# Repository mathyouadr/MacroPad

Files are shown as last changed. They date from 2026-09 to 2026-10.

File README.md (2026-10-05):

# MacroPad

Pavé de 9 touches programmables basé sur un Raspberry Pi Pico (RP2040) sous CircuitPython.
Il se branche en USB et est reconnu comme un clavier (raccourcis + touches média), sans driver.
Un logiciel PC permet de changer l'action de chaque touche sans reprogrammer le Pico.

Projet réalisé par Mathyou ANDRE dans le cadre du chef-d'œuvre Bac Pro CIEL, au LPP Le Marais Sainte-Thérèse.

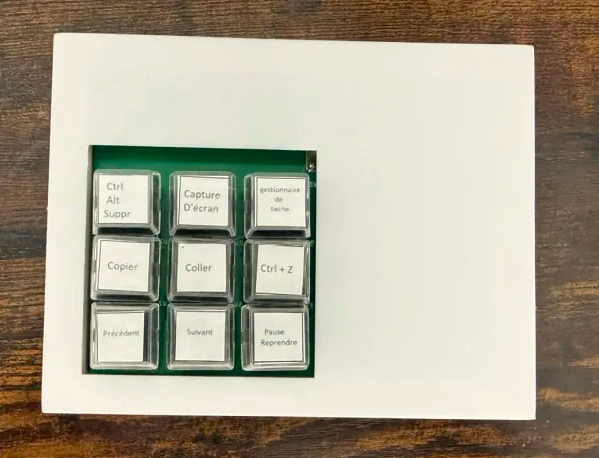
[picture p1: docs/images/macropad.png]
MacroPad assemblé


## Sommaire

- [Structure du projet](#structure-du-projet)
- [Firmware](#firmware)
- [Configurateur PC](#configurateur-pc)
- [Configuration des touches](#configuration-des-touches)
- [Matériel](#matériel)
- [Licence](#licence)

## Structure du projet

```text
MACROPAD/
├── firmware/        Code CircuitPython à copier sur le Pico (boot.py, code.py)
├── configurator/    Logiciel PC de configuration (Python / Tkinter)
├── hardware/
│   ├── schematic/   Schéma électronique (PDF, PNG, source EasyEDA)
│   ├── pcb/         PCB : source Fritzing, Gerber pour la fabrication, PDF
│   ├── case/        Boîtier 3D (Fusion 360 + STL pour l'impression)
│   └── libraries/   Composants Fritzing nécessaires pour ouvrir le PCB
└── docs/            Images du README
```

## Firmware

Code CircuitPython du dossier `firmware/`, à copier sur le Raspberry Pi Pico.

- `code.py` : lit les 9 touches, envoie les raccourcis clavier/média en USB HID,
  et reçoit la configuration du logiciel PC par le port série.
- `boot.py` : cache le lecteur `CIRCUITPY` au démarrage (voir [Mode maintenance](#mode-maintenance)).

### Installation

1. Installer CircuitPython sur le Pico (fichier `.uf2` depuis circuitpython.org).
2. Copier le dossier `adafruit_hid` de l'*Adafruit CircuitPython Library Bundle*
   dans `CIRCUITPY/lib/`.
3. Copier `firmware/code.py` puis `firmware/boot.py` à la racine de `CIRCUITPY`.
4. Débrancher puis rebrancher le Pico (`boot.py` ne s'exécute qu'au démarrage).

### Mode maintenance

Une fois `boot.py` installé, le lecteur `CIRCUITPY` n'apparaît plus sur le PC.
Pour y accéder à nouveau (mise à jour du code), **maintenir SW1 enfoncé en branchant le Pico**.

## Configurateur PC

Logiciel Python / Tkinter du dossier `configurator/`, pour lire et modifier l'action de chaque touche.

### Lancement

Nécessite Python 3 :

```bash
cd configurator
pip install -r requirements.txt
python main.py
```

### Utilisation

1. Brancher le MacroPad, choisir son port COM puis cliquer sur **Connecter**.
   La configuration actuelle du Pico est chargée automatiquement.
2. Modifier les touches. En type `keyboard`, écrire les touches séparées par `+`
   (ex. `CONTROL+SHIFT+ESCAPE`) ; en type `media`, écrire l'action (ex. `PLAY_PAUSE`).
   Voir les [valeurs possibles](#valeurs-possibles).
3. Cliquer sur **Envoyer au Pico**.

Les boutons **Sauvegarder / Charger fichier** utilisent `macropad_config.json`
dans le dossier courant.

### Générer un exécutable Windows (optionnel)

Pour utiliser le configurateur sur un PC sans Python :

```bash
cd configurator
pip install pyinstaller
pyinstaller main.spec
```

L'exécutable est créé dans `configurator/dist/MacroPad-Configurator.exe`.

## Configuration des touches

### Configuration par défaut

| Touche | GPIO | Action |
|---|---|---|
| SW1 | GP28 | Ctrl + Alt + Suppr |
| SW2 | GP27 | Capture d'écran (Win + Shift + S) |
| SW3 | GP26 | Gestionnaire des tâches (Ctrl + Shift + Échap) |
| SW4 | GP22 | Copier (Ctrl + C) |
| SW5 | GP21 | Coller (Ctrl + V) |
| SW6 | GP20 | Fermer l'onglet (Ctrl + W) |
| SW7 | GP19 | Piste précédente |
| SW8 | GP18 | Piste suivante |
| SW9 | GP17 | Lecture / Pause |

### Valeurs possibles

- **Touches clavier** : `A`–`Z`, `F1`–`F12`, `CONTROL`, `ALT`, `SHIFT`, `WINDOWS`,
  `DELETE`, `ESCAPE`, `ENTER`, `TAB`, `SPACE`
- **Actions média** : `PLAY_PAUSE`, `NEXT_TRACK`, `PREVIOUS_TRACK`,
  `VOLUME_UP`, `VOLUME_DOWN`, `MUTE`

### Stockage et protocole série

La configuration est stockée dans `/config.json` sur le Pico.
Si le fichier est absent, la configuration par défaut de `code.py` est utilisée.

Format d'une touche :

```json
{"sw1": {"type": "keyboard", "keys": ["CONTROL", "ALT", "DELETE"]},
 "sw9": {"type": "media", "action": "PLAY_PAUSE"}}
```

Commandes série (une par ligne) :

| Commande envoyée | Réponse du Pico |
|---|---|
| `GET_CONFIG` | `CONFIG_DATA:{...}` |
| `CONFIG:{...}` | `OK` ou `ERROR` |

## Matériel

Chaque switch relie son GPIO au 3V3. Le firmware active la résistance de pull-down interne.

- **Schéma** : `hardware/schematic/schematic.pdf`
- **PCB** : conçu avec Fritzing 0.9.9 (`hardware/pcb/MACROPAD-FRIT.fzz`).
  Pour l'ouvrir, importer d'abord les composants de `hardware/libraries/fritzing/`.
  Les fichiers de fabrication sont dans `hardware/pcb/gerber.rar` (visualisables avec gerbv).
- **Boîtier** : `hardware/case/macropad-case.stl` pour l'impression, `.f3d` pour le modifier dans Fusion 360.

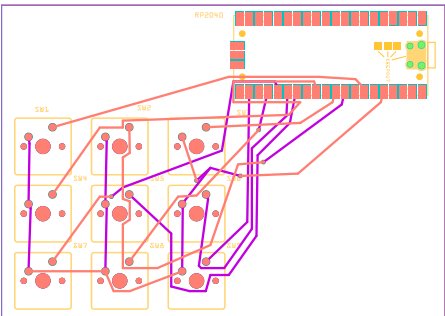
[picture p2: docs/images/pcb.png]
Routage du PCB


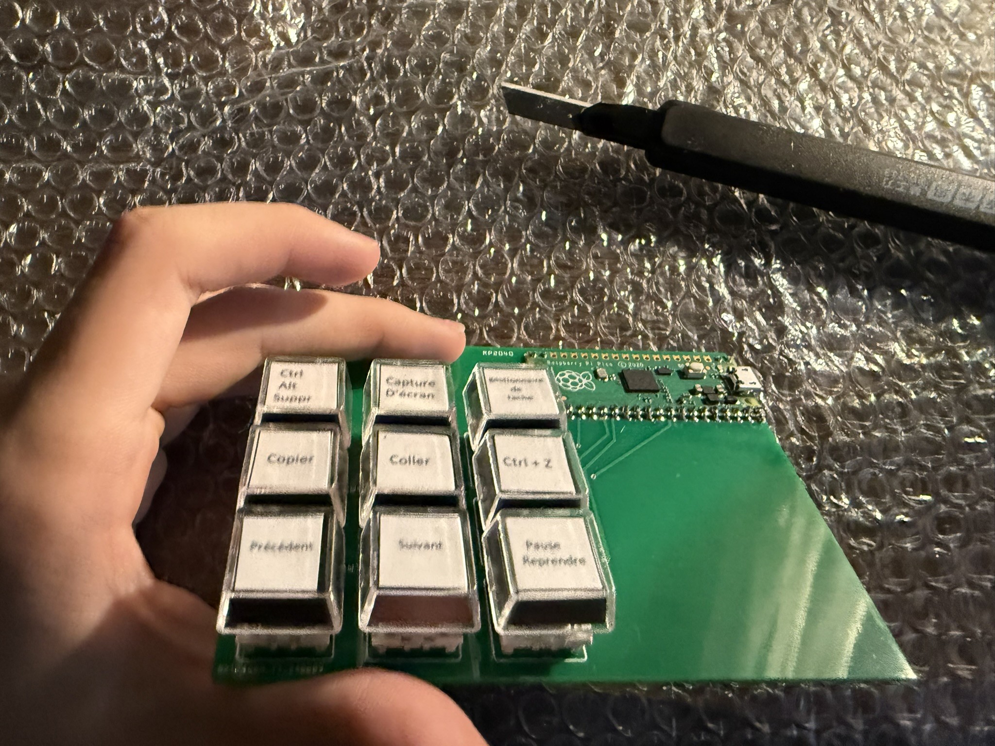
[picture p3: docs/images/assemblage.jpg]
Assemblage du PCB : soudure des switches mécaniques et du Raspberry Pi Pico


## Licence

MIT — voir [LICENSE](LICENSE).

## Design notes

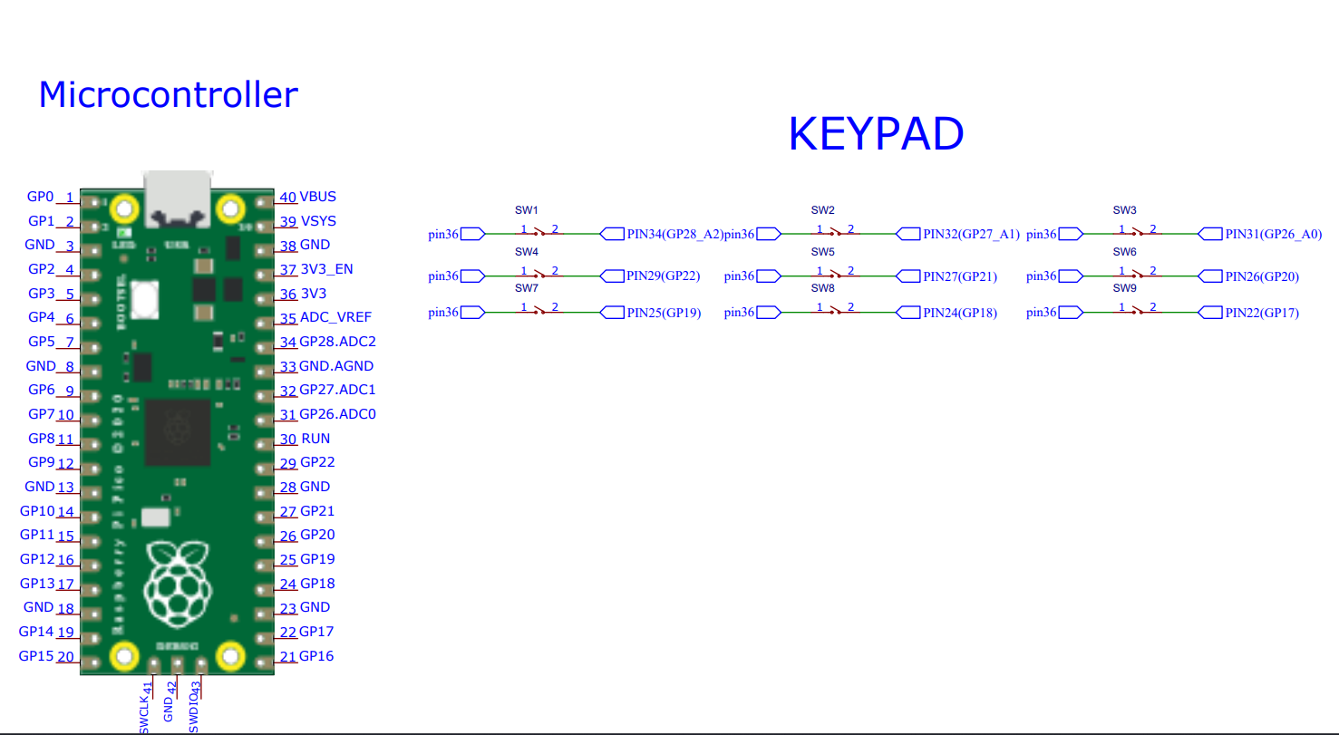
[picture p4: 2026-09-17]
hardware/schematic/schematic.png

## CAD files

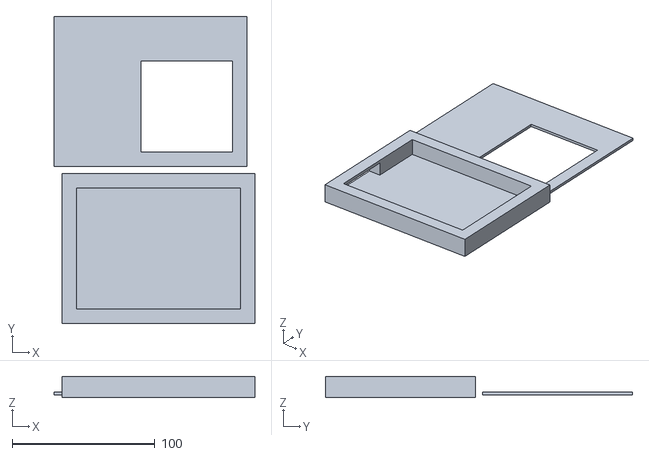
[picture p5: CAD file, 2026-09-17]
hardware/case/macropad-case.stl
140.7 x 215.0 x 15.0

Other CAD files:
hardware/case/macropad-case.f3d

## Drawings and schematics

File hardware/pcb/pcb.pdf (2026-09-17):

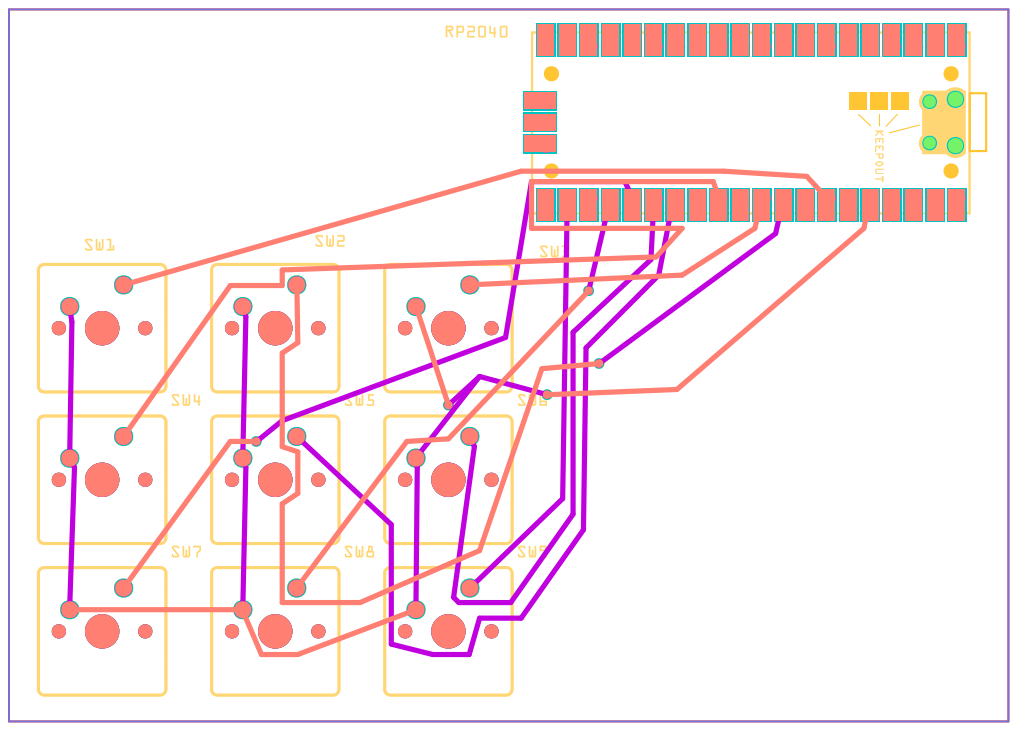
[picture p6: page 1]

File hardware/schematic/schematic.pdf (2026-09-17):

# Microcontroller

# KEYPAD

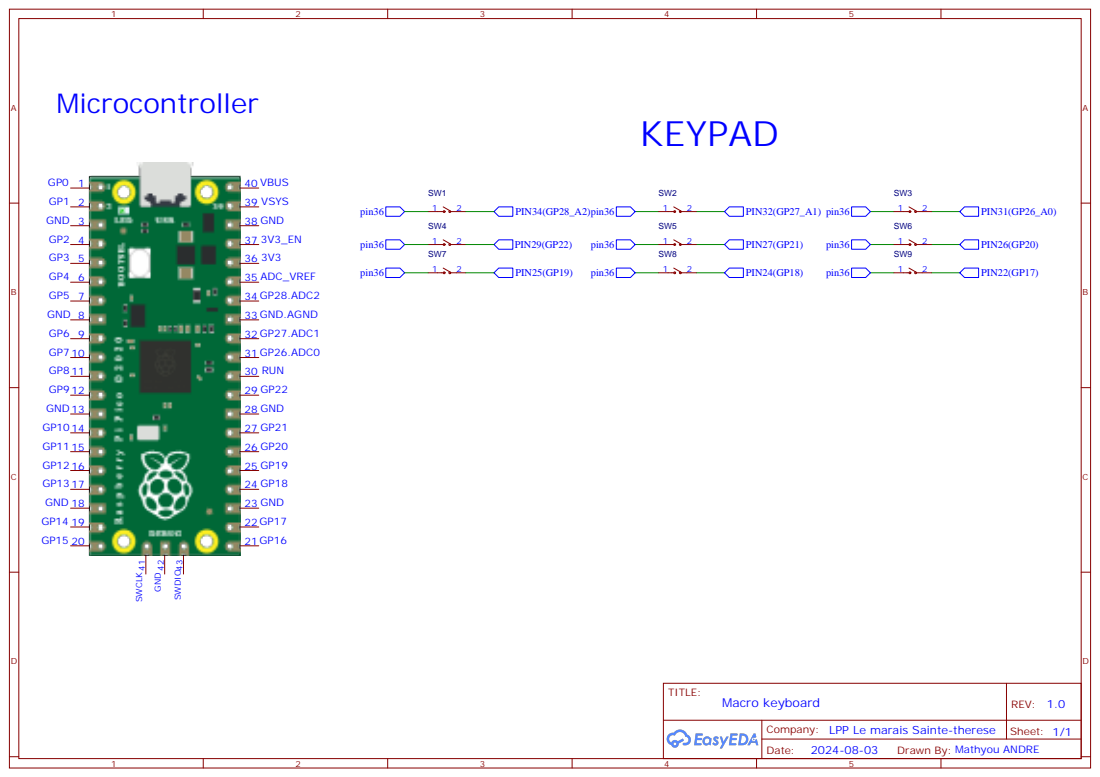
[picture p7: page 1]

Company: LPP Le marais Sainte-therese

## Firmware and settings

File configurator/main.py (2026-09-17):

import tkinter as tk
from tkinter import ttk, messagebox
import json
import serial
import serial.tools.list_ports
import time

class MacroPadConfigurator:
    def __init__(self, root):
        self.root = root
        self.root.title("Configurateur Macro Pad")
        self.root.geometry("800x600")
        
        self.serial_port = None
        self.config = self.load_default_config()
        
        self.create_ui()
        
    def load_default_config(self):
        """Configuration par défaut"""
        return {
            "sw1": {"type": "keyboard", "keys": ["CONTROL", "ALT", "DELETE"], "name": "Ctrl+Alt+Del"},
            "sw2": {"type": "keyboard", "keys": ["WINDOWS", "SHIFT", "S"], "name": "Screenshot"},
            "sw3": {"type": "keyboard", "keys": ["CONTROL", "SHIFT", "ESCAPE"], "name": "Task Manager"},
            "sw4": {"type": "keyboard", "keys": ["CONTROL", "C"], "name": "Copier"},
            "sw5": {"type": "keyboard", "keys": ["CONTROL", "V"], "name": "Coller"},
            "sw6": {"type": "keyboard", "keys": ["CONTROL", "W"], "name": "Fermer"},
            "sw7": {"type": "media", "action": "PREVIOUS_TRACK", "name": "Piste précédente"},
            "sw8": {"type": "media", "action": "NEXT_TRACK", "name": "Piste suivante"},
            "sw9": {"type": "media", "action": "PLAY_PAUSE", "name": "Play/Pause"},
        }
    
    def create_ui(self):
        # Frame de connexion
        conn_frame = ttk.LabelFrame(self.root, text="Connexion", padding=10)
        conn_frame.pack(fill="x", padx=10, pady=5)
        
        ttk.Label(conn_frame, text="Port:").grid(row=0, column=0, padx=5)
        self.port_combo = ttk.Combobox(conn_frame, width=30)
        self.port_combo.grid(row=0, column=1, padx=5)
        
        ttk.Button(conn_frame, text="Rafraîchir", command=self.refresh_ports).grid(row=0, column=2, padx=5)
        self.connect_btn = ttk.Button(conn_frame, text="Connecter", command=self.connect)
        self.connect_btn.grid(row=0, column=3, padx=5)
        
        self.status_label = ttk.Label(conn_frame, text="Déconnecté", foreground="red")
        self.status_label.grid(row=0, column=4, padx=5)
        
        # Frame de configuration
        config_frame = ttk.LabelFrame(self.root, text="Configuration des touches", padding=10)
        config_frame.pack(fill="both", expand=True, padx=10, pady=5)
        
        # Canvas avec scrollbar pour les boutons
        canvas = tk.Canvas(config_frame)
        scrollbar = ttk.Scrollbar(config_frame, orient="vertical", command=canvas.yview)
        scrollable_frame = ttk.Frame(canvas)
        
        scrollable_frame.bind(
            "<Configure>",
            lambda e: canvas.configure(scrollregion=canvas.bbox("all"))
        )
        
        canvas.create_window((0, 0), window=scrollable_frame, anchor="nw")
        canvas.configure(yscrollcommand=scrollbar.set)
        
        canvas.pack(side="left", fill="both", expand=True)
        scrollbar.pack(side="right", fill="y")
        
        # Créer les configurations pour chaque bouton
        self.button_frames = {}
        for i in range(1, 10):
            sw_name = f"sw{i}"
            self.create_button_config(scrollable_frame, sw_name, i-1)
        
        # Frame de contrôle
        control_frame = ttk.Frame(self.root)
        control_frame.pack(fill="x", padx=10, pady=5)
        
        ttk.Button(control_frame, text="📥 Lire config du Pico", command=self.read_config_from_pico).pack(side="left", padx=5)
        ttk.Button(control_frame, text="📤 Envoyer au Pico", command=self.send_config).pack(side="left", padx=5)
        ttk.Button(control_frame, text="💾 Charger fichier", command=self.load_config).pack(side="left", padx=5)
        ttk.Button(control_frame, text="💾 Sauvegarder fichier", command=self.save_config).pack(side="left", padx=5)
        
        self.refresh_ports()
    
    def create_button_config(self, parent, sw_name, row):
        frame = ttk.LabelFrame(parent, text=f"Bouton {sw_name.upper()}", padding=5)
        frame.grid(row=row, column=0, sticky="ew", pady=5, padx=5)
        parent.columnconfigure(0, weight=1)
        
        # Nom
        ttk.Label(frame, text="Nom:").grid(row=0, column=0, sticky="w", padx=5)
        name_entry = ttk.Entry(frame, width=30)
        name_entry.grid(row=0, column=1, sticky="ew", padx=5)
        name_entry.insert(0, self.config[sw_name]["name"])
        
        # Type
        ttk.Label(frame, text="Type:").grid(row=1, column=0, sticky="w", padx=5)
        type_combo = ttk.Combobox(frame, values=["keyboard", "media"], state="readonly", width=28)
        type_combo.grid(row=1, column=1, sticky="ew", padx=5)
        type_combo.set(self.config[sw_name]["type"])
        
        # Configuration
        config_label = ttk.Label(frame, text="Config:")
        config_label.grid(row=2, column=0, sticky="w", padx=5)
        config_entry = ttk.Entry(frame, width=30)
        config_entry.grid(row=2, column=1, sticky="ew", padx=5)
        
        if self.config[sw_name]["type"] == "keyboard":
            config_entry.insert(0, "+".join(self.config[sw_name]["keys"]))
        else:
            config_entry.insert(0, self.config[sw_name]["action"])
        
        frame.columnconfigure(1, weight=1)
        
        # Stocker les widgets pour récupération
        self.button_frames[sw_name] = {
            "name": name_entry,
            "type": type_combo,
            "config": config_entry
        }
    
    def refresh_ports(self):
        ports = [port.device for port in serial.tools.list_ports.comports()]
        self.port_combo['values'] = ports
        if ports:
            self.port_combo.current(0)
    
    def connect(self):
        if self.serial_port and self.serial_port.is_open:
            self.serial_port.close()
            self.serial_port = None
            self.status_label.config(text="Déconnecté", foreground="red")
            self.connect_btn.config(text="Connecter")
        else:
            try:
                port = self.port_combo.get()
                self.serial_port = serial.Serial(port, 115200, timeout=1)
                time.sleep(2)  # Attendre la connexion
                self.status_label.config(text=f"Connecté sur {port}", foreground="green")
                self.connect_btn.config(text="Déconnecter")
                
                # Lire automatiquement la config du Pico
                self.read_config_from_pico()
                
            except Exception as e:
                messagebox.showerror("Erreur", f"Impossible de se connecter: {str(e)}")
    
    def read_config_from_pico(self):
        """Lit la configuration actuelle du Pico"""
        if not self.serial_port or not self.serial_port.is_open:
            messagebox.showwarning("Attention", "Veuillez vous connecter au macro pad d'abord")
            return
        
        try:
            # Vider les buffers
            self.serial_port.reset_input_buffer()
            self.serial_port.reset_output_buffer()
            
            # Demander la config au Pico
            self.serial_port.write(b"GET_CONFIG\n")
            
            # Attendre la réponse (max 2 secondes)
            timeout = time.time() + 2
            response = ""
            
            while time.time() < timeout:
                if self.serial_port.in_waiting > 0:
                    data = self.serial_port.read(self.serial_port.in_waiting).decode('utf-8', errors='ignore')
                    response += data
                    
                    # Si on a reçu une ligne complète avec CONFIG_DATA:
                    if "CONFIG_DATA:" in response:
                        break
                time.sleep(0.1)
            
            print(f"Réponse brute: {response}")  # Debug
            
            # Extraire le JSON de la réponse
            if "CONFIG_DATA:" in response:
                # Trouver la ligne qui commence par CONFIG_DATA:
                for line in response.split('\n'):
                    if line.startswith("CONFIG_DATA:"):
                        json_str = line[12:].strip()  # Enlever "CONFIG_DATA:"
                        print(f"JSON reçu: {json_str}")  # Debug
                        
                        pico_config = json.loads(json_str)
                        
                        # Mettre à jour l'interface avec la config du Pico
                        for sw_name, sw_config in pico_config.items():
                            if sw_name in self.button_frames:
                                widgets = self.button_frames[sw_name]
                                
                                # Nom (garder celui actuel si absent du Pico)
                                if "name" in sw_config:
                                    widgets["name"].delete(0, tk.END)
                                    widgets["name"].insert(0, sw_config["name"])
                                
                                # Type
                                widgets["type"].set(sw_config["type"])
                                
                                # Config
                                widgets["config"].delete(0, tk.END)
                                if sw_config["type"] == "keyboard":
                                    widgets["config"].insert(0, "+".join(sw_config["keys"]))
                                else:
                                    widgets["config"].insert(0, sw_config["action"])
                        
                        messagebox.showinfo("Succès", "Configuration du Pico chargée !")
                        return
            
            messagebox.showwarning("Attention", "Pas de réponse du Pico. Vérifiez le code.py")
            
        except json.JSONDecodeError as e:
            messagebox.showerror("Erreur", f"Erreur de parsing JSON: {str(e)}\nRéponse: {response}")
        except Exception as e:
            messagebox.showerror("Erreur", f"Erreur lors de la lecture: {str(e)}")
    
    def test_connection(self):
        """Test la connexion série en envoyant un simple message"""
        if not self.serial_port or not self.serial_port.is_open:
            messagebox.showwarning("Attention", "Veuillez vous connecter au macro pad d'abord")
            return
        
        try:
            # Vider le buffer
            self.serial_port.reset_input_buffer()
            self.serial_port.reset_output_buffer()
            
            # Envoyer un test
            self.serial_port.write(b"TEST\n")
            messagebox.showinfo("Test", "Commande de test envoyée")
        except Exception as e:
            messagebox.showerror("Erreur", f"Erreur de test: {str(e)}")
    
    def get_current_config(self):
        """Récupère la configuration depuis l'interface"""
        config = {}
        for sw_name, widgets in self.button_frames.items():
            sw_type = widgets["type"].get()
            config_str = widgets["config"].get()
            
            config[sw_name] = {
                "name": widgets["name"].get(),
                "type": sw_type
            }
            
            if sw_type == "keyboard":
                config[sw_name]["keys"] = [k.strip() for k in config_str.split("+")]
            else:
                config[sw_name]["action"] = config_str
        
        return config
    
    def send_config(self):
        if not self.serial_port or not self.serial_port.is_open:
            messagebox.showwarning("Attention", "Veuillez vous connecter au macro pad d'abord")
            return
        
        try:
            config = self.get_current_config()
            
            # Préparer le JSON (enlever les champs "name" pour le Pico)
            pico_config = {}
            for sw_name, sw_data in config.items():
                pico_config[sw_name] = {
                    "type": sw_data["type"]
                }
                if sw_data["type"] == "keyboard":
                    pico_config[sw_name]["keys"] = sw_data["keys"]
                else:
                    pico_config[sw_name]["action"] = sw_data["action"]
            
            json_config = json.dumps(pico_config)
            
            # Vider les buffers
            self.serial_port.reset_input_buffer()
            self.serial_port.reset_output_buffer()
            
            # Envoyer la configuration
            message = f"CONFIG:{json_config}\n"
            print(f"Envoi: {message}")  # Debug
            self.serial_port.write(message.encode('utf-8'))
            
            # Attendre la réponse
            time.sleep(0.5)
            if self.serial_port.in_waiting > 0:
                response = self.serial_port.read(self.serial_port.in_waiting).decode('utf-8', errors='ignore')
                print(f"Réponse: {response}")  # Debug
                if "OK" in response:
                    messagebox.showinfo("Succès", "Configuration envoyée et confirmée !")
                else:
                    messagebox.showwarning("Attention", f"Réponse du Pico: {response}")
            else:
                messagebox.showinfo("Envoyé", "Configuration envoyée (pas de réponse)")
                
        except Exception as e:
            messagebox.showerror("Erreur", f"Erreur lors de l'envoi: {str(e)}")
    
    def save_config(self):
        try:
            config = self.get_current_config()
            with open("macropad_config.json", "w") as f:
                json.dump(config, f, indent=2)
            messagebox.showinfo("Succès", "Configuration sauvegardée dans macropad_config.json")
        except Exception as e:
            messagebox.showerror("Erreur", f"Erreur lors de la sauvegarde: {str(e)}")
    
    def load_config(self):
        try:
            with open("macropad_config.json", "r") as f:
                config = json.load(f)
            
            # Mettre à jour l'interface
            for sw_name, sw_config in config.items():
                if sw_name in self.button_frames:
                    widgets = self.button_frames[sw_name]
                    widgets["name"].delete(0, tk.END)
                    widgets["name"].insert(0, sw_config["name"])
                    widgets["type"].set(sw_config["type"])
                    
                    widgets["config"].delete(0, tk.END)
                    if sw_config["type"] == "keyboard":
                        widgets["config"].insert(0, "+".join(sw_config["keys"]))
                    else:
                        widgets["config"].insert(0, sw_config["action"])
            
            messagebox.showinfo("Succès", "Configuration chargée")
        except FileNotFoundError:
            messagebox.showwarning("Attention", "Fichier de configuration non trouvé")
        except Exception as e:
            messagebox.showerror("Erreur", f"Erreur lors du chargement: {str(e)}")

if __name__ == "__main__":
    root = tk.Tk()
    app = MacroPadConfigurator(root)
    root.mainloop()

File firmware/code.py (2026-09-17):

import board
import digitalio
import time
import usb_hid
import usb_cdc
import json
from adafruit_hid.keyboard import Keyboard
from adafruit_hid.keycode import Keycode
from adafruit_hid.consumer_control import ConsumerControl
from adafruit_hid.consumer_control_code import ConsumerControlCode

# Initialisation du clavier HID
keyboard = Keyboard(usb_hid.devices)
cc = ConsumerControl(usb_hid.devices)

# Port série pour la communication
serial = usb_cdc.console

# Mapping des noms de touches vers les codes Keycode
KEYCODE_MAP = {
    "CONTROL": Keycode.CONTROL,
    "ALT": Keycode.ALT,
    "DELETE": Keycode.DELETE,
    "WINDOWS": Keycode.WINDOWS,
    "SHIFT": Keycode.SHIFT,
    "S": Keycode.S,
    "ESCAPE": Keycode.ESCAPE,
    "C": Keycode.C,
    "V": Keycode.V,
    "W": Keycode.W,
    "A": Keycode.A,
    "B": Keycode.B,
    "D": Keycode.D,
    "E": Keycode.E,
    "F": Keycode.F,
    "G": Keycode.G,
    "H": Keycode.H,
    "I": Keycode.I,
    "J": Keycode.J,
    "K": Keycode.K,
    "L": Keycode.L,
    "M": Keycode.M,
    "N": Keycode.N,
    "O": Keycode.O,
    "P": Keycode.P,
    "Q": Keycode.Q,
    "R": Keycode.R,
    "T": Keycode.T,
    "U": Keycode.U,
    "X": Keycode.X,
    "Y": Keycode.Y,
    "Z": Keycode.Z,
    "ENTER": Keycode.ENTER,
    "TAB": Keycode.TAB,
    "SPACE": Keycode.SPACE,
    "F1": Keycode.F1,
    "F2": Keycode.F2,
    "F3": Keycode.F3,
    "F4": Keycode.F4,
    "F5": Keycode.F5,
    "F6": Keycode.F6,
    "F7": Keycode.F7,
    "F8": Keycode.F8,
    "F9": Keycode.F9,
    "F10": Keycode.F10,
    "F11": Keycode.F11,
    "F12": Keycode.F12,
}

MEDIA_MAP = {
    "PLAY_PAUSE": ConsumerControlCode.PLAY_PAUSE,
    "NEXT_TRACK": ConsumerControlCode.SCAN_NEXT_TRACK,
    "PREVIOUS_TRACK": ConsumerControlCode.SCAN_PREVIOUS_TRACK,
    "VOLUME_UP": ConsumerControlCode.VOLUME_INCREMENT,
    "VOLUME_DOWN": ConsumerControlCode.VOLUME_DECREMENT,
    "MUTE": ConsumerControlCode.MUTE,
}

# Configuration par défaut
default_config = {
    "sw1": {"type": "keyboard", "keys": ["CONTROL", "ALT", "DELETE"]},
    "sw2": {"type": "keyboard", "keys": ["WINDOWS", "SHIFT", "S"]},
    "sw3": {"type": "keyboard", "keys": ["CONTROL", "SHIFT", "ESCAPE"]},
    "sw4": {"type": "keyboard", "keys": ["CONTROL", "C"]},
    "sw5": {"type": "keyboard", "keys": ["CONTROL", "V"]},
    "sw6": {"type": "keyboard", "keys": ["CONTROL", "W"]},
    "sw7": {"type": "media", "action": "PREVIOUS_TRACK"},
    "sw8": {"type": "media", "action": "NEXT_TRACK"},
    "sw9": {"type": "media", "action": "PLAY_PAUSE"},
}

# Configuration actuelle
config = default_config.copy()

# Configuration des switches
switches = {
    "sw1": board.GP28,
    "sw2": board.GP27,
    "sw3": board.GP26,
    "sw4": board.GP22,
    "sw5": board.GP21,
    "sw6": board.GP20,
    "sw7": board.GP19,
    "sw8": board.GP18,
    "sw9": board.GP17,
}

# Initialisation des pins
switch_pins = {}
for name, pin in switches.items():
    sw = digitalio.DigitalInOut(pin)
    sw.direction = digitalio.Direction.INPUT
    sw.pull = digitalio.Pull.DOWN
    switch_pins[name] = sw

# État précédent des boutons pour détecter les appuis
previous_state = {name: False for name in switches.keys()}

# Buffer pour la réception série
serial_buffer = ""

def load_config_from_file():
    """Charge la configuration depuis le fichier config.json"""
    global config
    try:
        with open("/config.json", "r") as f:
            config = json.load(f)
        print("Configuration chargée depuis le fichier")
    except:
        print("Pas de fichier de configuration, utilisation de la config par défaut")
        config = default_config.copy()

def save_config_to_file():
    """Sauvegarde la configuration dans config.json"""
    try:
        with open("/config.json", "w") as f:
            json.dump(config, f)
        print("Configuration sauvegardée")
    except Exception as e:
        print(f"Erreur sauvegarde: {e}")

def execute_action(sw_name):
    """Exécute l'action configurée pour un switch"""
    if sw_name not in config:
        return
    
    action_config = config[sw_name]
    
    if action_config["type"] == "keyboard":
        # Convertir les noms de touches en keycodes
        keycodes = []
        for key_name in action_config["keys"]:
            if key_name in KEYCODE_MAP:
                keycodes.append(KEYCODE_MAP[key_name])
        
        if keycodes:
            keyboard.press(*keycodes)
            keyboard.release_all()
    
    elif action_config["type"] == "media":
        action_name = action_config["action"]
        if action_name in MEDIA_MAP:
            cc.send(MEDIA_MAP[action_name])

def check_serial_config():
    """Vérifie si une nouvelle configuration est reçue via série (NON BLOQUANT)"""
    global config, serial_buffer
    
    # Vérifier s'il y a des données disponibles
    if serial and serial.in_waiting > 0:
        try:
            # Lire les données disponibles
            data = serial.read(serial.in_waiting)
            if data:
                try:
                    serial_buffer += data.decode('utf-8')
                except:
                    serial_buffer += data.decode('utf-8', 'ignore')
                
                # Chercher une ligne complète (terminée par \n)
                if '\n' in serial_buffer:
                    lines = serial_buffer.split('\n')
                    for line in lines[:-1]:  # Traiter toutes les lignes complètes
                        line = line.strip()
                        
                        # Commande pour recevoir une nouvelle config
                        if line.startswith("CONFIG:"):
                            try:
                                json_str = line[7:]  # Enlever "CONFIG:"
                                new_config = json.loads(json_str)
                                config = new_config
                                save_config_to_file()
                                print("Configuration mise a jour!")
                                serial.write(b"OK\n")
                            except Exception as e:
                                print(f"Erreur parsing config: {e}")
                                serial.write(b"ERROR\n")
                        
                        # Commande pour envoyer la config actuelle
                        elif line == "GET_CONFIG":
                            try:
                                json_config = json.dumps(config)
                                serial.write(f"CONFIG_DATA:{json_config}\n".encode('utf-8'))
                                print("Config envoyee au PC")
                            except Exception as e:
                                print(f"Erreur envoi config: {e}")
                                serial.write(b"ERROR\n")
                    
                    # Garder la dernière partie incomplète dans le buffer
                    serial_buffer = lines[-1]
        except Exception as e:
            print(f"Erreur lecture serie: {e}")
            serial_buffer = ""
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

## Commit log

2026-09-17 Premier commit : firmware, configurateur PC et fichiers matériel du MacroPad
    [MACROPAD-FRIT.fzz, macropad-case.f3d, macropad-case.stl]
2026-09-17 Regroupe la documentation dans un seul README
2026-10-05 docs: add PCB assembly photo to README
